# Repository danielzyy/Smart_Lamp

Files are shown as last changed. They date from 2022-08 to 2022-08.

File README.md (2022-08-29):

# Smart_Lamp
Smart lamp built with Adafruit Circuit Playground Express board.

Three modes (manual light, sound light, and alarm) are cycled through by pressing the mode button on the back left of the lamp.
The slide switch on the board toggles between two light modes(solid ring color cycle and rainbow ring cycle).
The left and right buttons on the board are also used in the sound light and alarm modes.
## Modes
### Manual Light (Mode 0)
<b>Two lighting modes: </b> <br>
| Solid Ring Color Cycle (Slide switch to the left) | Rainbow Ring Cycle (Slide switch to the right) |
| --- | --- |
| |  |

<b>Brightness Control Using Rotary Encoder</b>
* Turning left increases brightness of lamp
* Turning right decreases brightness of lamp
* Pressing on the rotary encoder pauses/resumes the color cycle in solid ring color cycle mode.

### Sound Light (Mode 1)
Lights are triggered by noise that exceeds the sound limit. The sound limit is displayed at the top of the display and can be increased or decreased using the left and right buttons on the board.

Brightness of the lights are still controlled by the rotary encoder(same as Mode 0).

### Alarm (Mode 2)
Alarm time is set with the left and right buttons on the board (left button increases hours and right button increases minutes). Pressing on the encoder turns the alarm on. The status of the alarm is displayed at the top of the screen (ON/OFF). <b> Must switch back to Mode 0 or 1 after turning on alarm for it to ring. </b><br>

To turn off ringing alarm, hold down the encoder button until ringing stops.

## Circuit
[Schematic Diagram](https://github.com/danielzyy/Smart_Lamp/tree/main/Circuit%20Schematic)

 

## 3D Model Assembly
[Assembly and Part files (With STL)](https://github.com/danielzyy/Smart_Lamp/tree/main/Solidworks%20Models)

* Top compartment slides over Adafruit board to diffuse light
* Middle compartment holds all electronic components except for the RTC
* Bottom compartment holds hte RTC and any batteries needed, with cables routed through to the middle compartment
* All parts were 3D printed with 25% density



## Bill of Materials
Component                           | Qty | Link
------------------------------------| :-: | ----
Adafruit Circuit Playground Express | 1 | https://www.adafruit.com/product/3333
SSD1306 128x32 OLED Display         | 1 | https://www.amazon.ca/dp/B085NHM5TC
DS1307 AT24C32 RTC                  | 1 | https://www.amazon.ca/dp/B07GGM7GL4
Rechargable 3.6V Coin Cell for RTC  | 1 | https://www.amazon.ca/dp/B09TTSNM31
Rotary Encoder with Push Button     | 1 | https://www.amazon.ca/dp/B08728K3YB
Push Button                         | 1 | https://www.amazon.ca/dp/B07DFDS7W8
Resistor 220Ohm                     | 2 | https://www.digikey.com/en/products/detail/stackpole-electronics-inc/CF18JT220R/1741639
Resistor 10kOhm                     | 2 | https://www.digikey.com/en/products/detail/stackpole-electronics-inc/CF14JT10K0/1741265
Capacitor 1uF                       | 2 | https://www.digikey.com/en/products/detail/murata-electronics/RDER71H105K2M1H03A/4771301

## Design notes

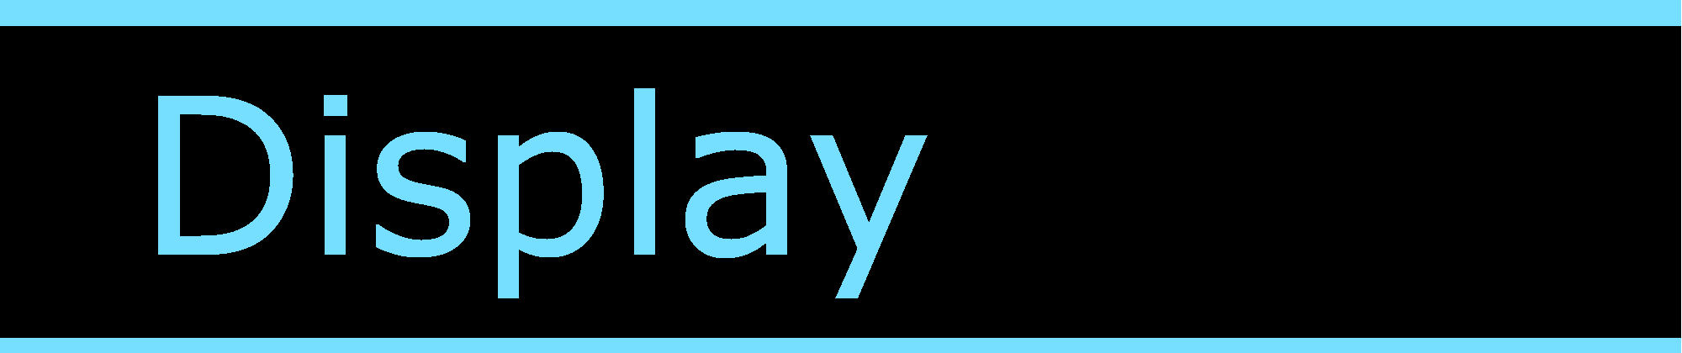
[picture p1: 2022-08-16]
Solidworks Models/Display.png

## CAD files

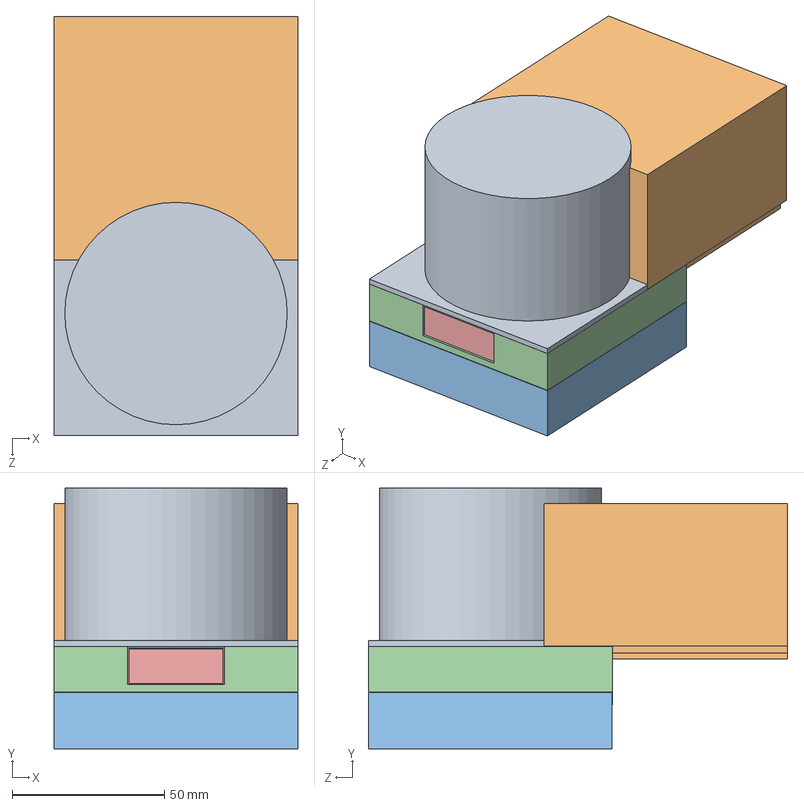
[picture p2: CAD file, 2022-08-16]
Solidworks Models/lamp_asm.SLDASM
80.0 x 85.7 x 137.6 mm
battery_base
board_base
Board.step
10uF.step x 2
10K.step x 17
RED.step x 2
KMR2.step
MicroB USB.step
3-6VDC.step
MBR120.step x 2
EG1390.step
EVQQ.step x 2
WS2812B3535.step x 10
LIS3DH.step
ALS-PT19-315C.step
THERM.step
AP2112K-3.3.step
7.5mm SPK.step
ATSAMD21G18MU.step
SPI FLASH.step
6V+ 500mA.step
MIC_PDM.step
VSOP383.step
IR TX.step x 2
PAM8301.step
mmbt2222.step
OLED_Display_32x128
lamp_top_square
lamp_top_circle_cover

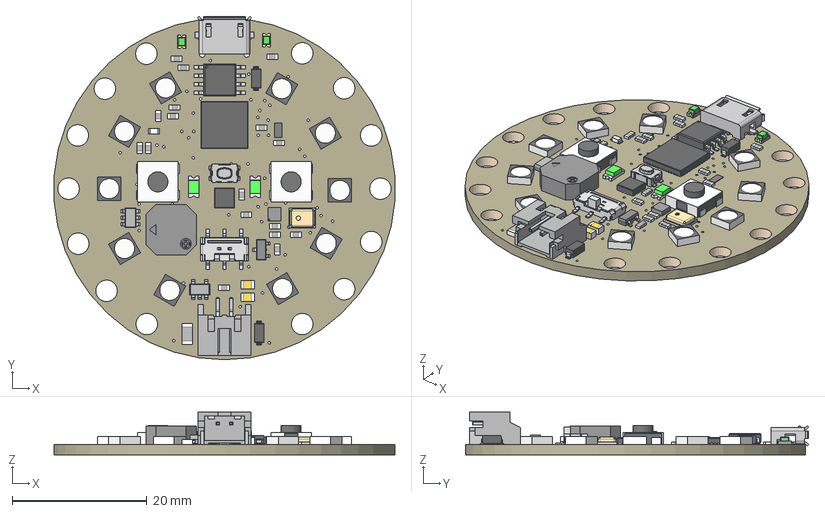
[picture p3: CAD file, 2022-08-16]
Solidworks Models/3333 Circuit Playground Express.step
50.7 x 51.1 x 6.37 mm
Board
10uF x 2
10K x 17
RED x 2
KMR2
MicroB USB
3-6VDC
MBR120 x 2
EG1390
EVQQ x 2
WS2812B3535 x 10
LIS3DH
ALS-PT19-315C
THERM
AP2112K-3.3
7.5mm SPK
ATSAMD21G18MU
SPI FLASH
6V+ 500mA
MIC_PDM
VSOP383
IR TX x 2
PAM8301
mmbt2222

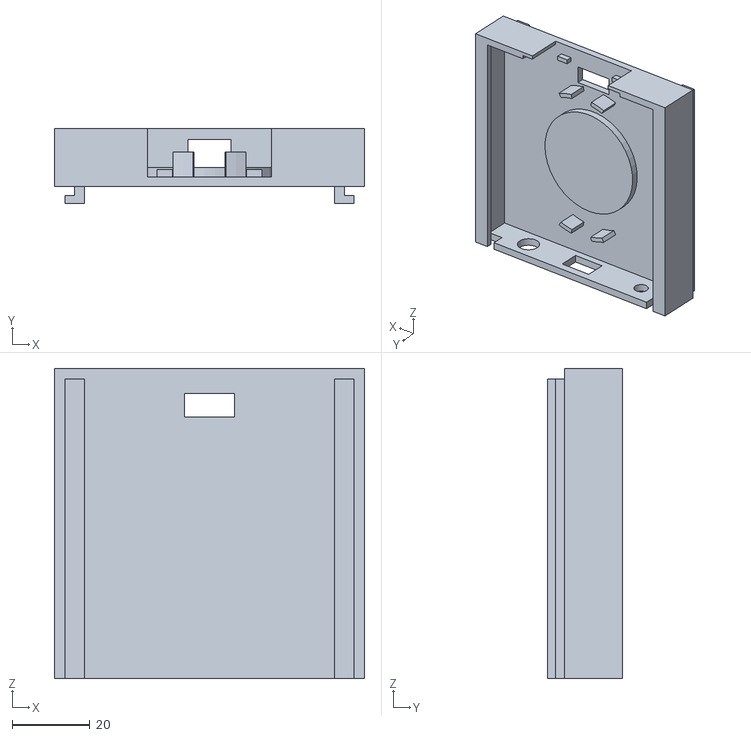
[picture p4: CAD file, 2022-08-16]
Solidworks Models/board_basev2.STL
80.0 x 19.3 x 80.0

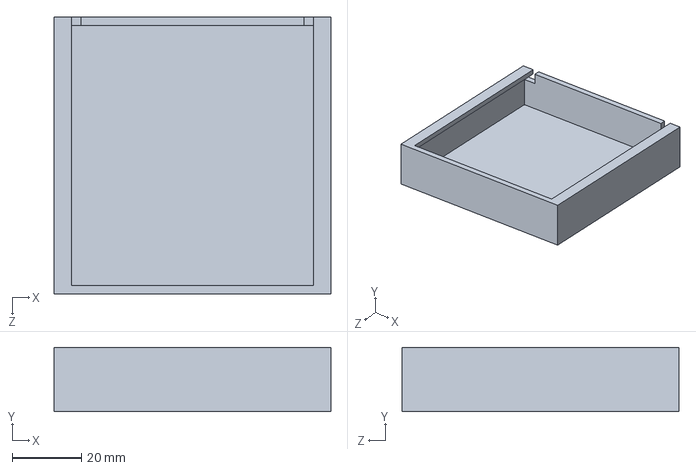
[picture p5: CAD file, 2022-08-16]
Solidworks Models/battery_base.SLDPRT
80.0 x 18.5 x 80.0 mm

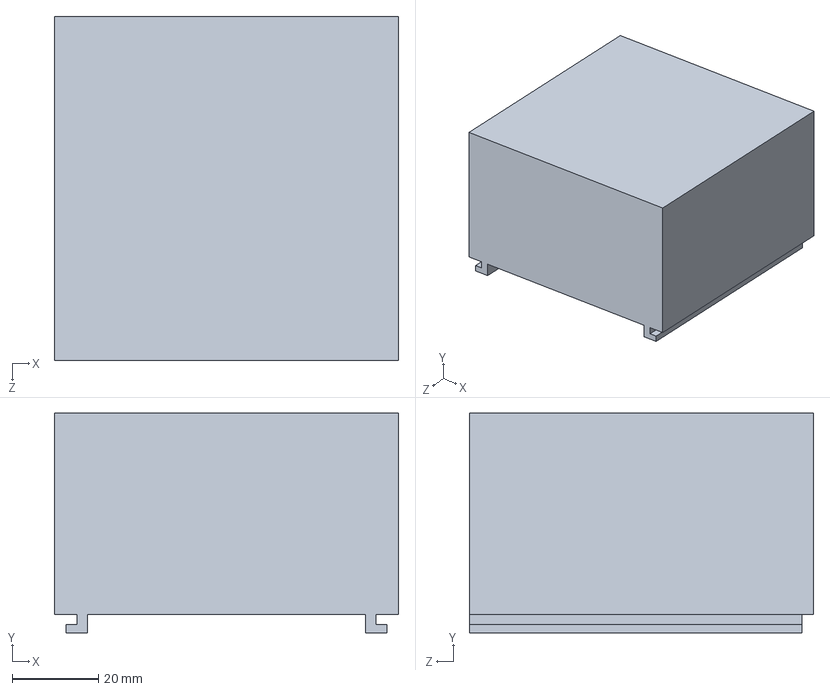
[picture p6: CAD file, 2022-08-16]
Solidworks Models/lamp_top_square.SLDPRT
80.0 x 51.1 x 80.0 mm

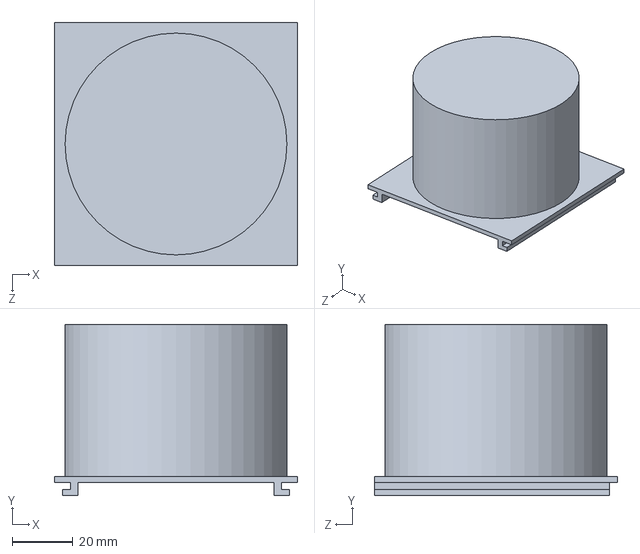
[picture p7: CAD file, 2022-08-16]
Solidworks Models/lamp_top_circle_cover.SLDPRT
80.0 x 56.3 x 80.0 mm

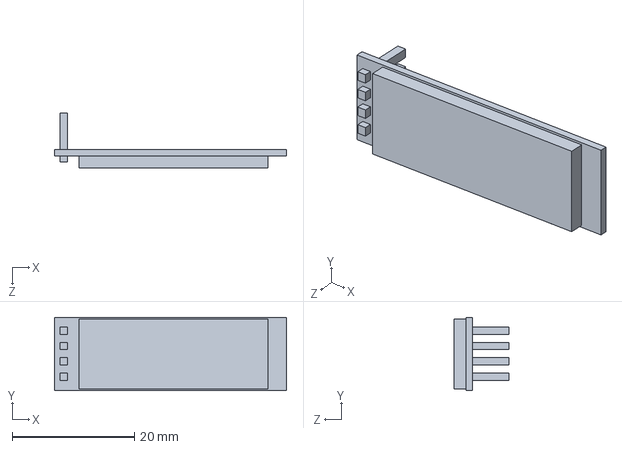
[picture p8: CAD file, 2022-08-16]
Solidworks Models/OLED_Display_32x128.SLDPRT
38.0 x 12.0 x 9.00 mm

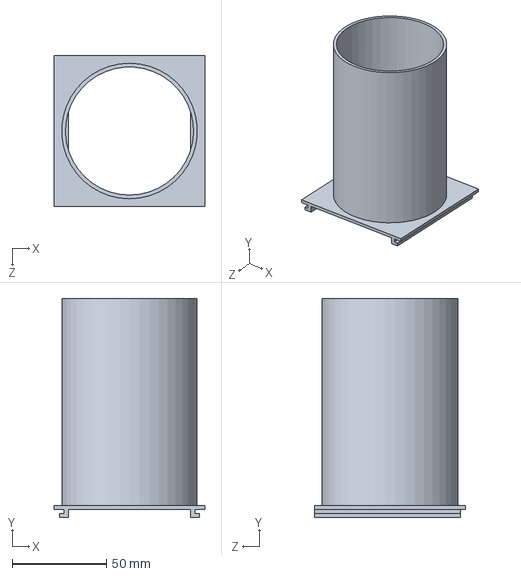
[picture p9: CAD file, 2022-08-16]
Solidworks Models/lamp_top.SLDPRT
80.0 x 116.3 x 80.0 mm

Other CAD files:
Solidworks Models/board_base.SLDPRT
Solidworks Models/3333 CircuitPlaygroundExpress.SLDPRT
Solidworks Models/3333 CircuitPlaygroundExpress.stl
Solidworks Models/battery_base.STL
Solidworks Models/lamp_top_circle_cover.STL
Solidworks Models/lamp_top_square.STL

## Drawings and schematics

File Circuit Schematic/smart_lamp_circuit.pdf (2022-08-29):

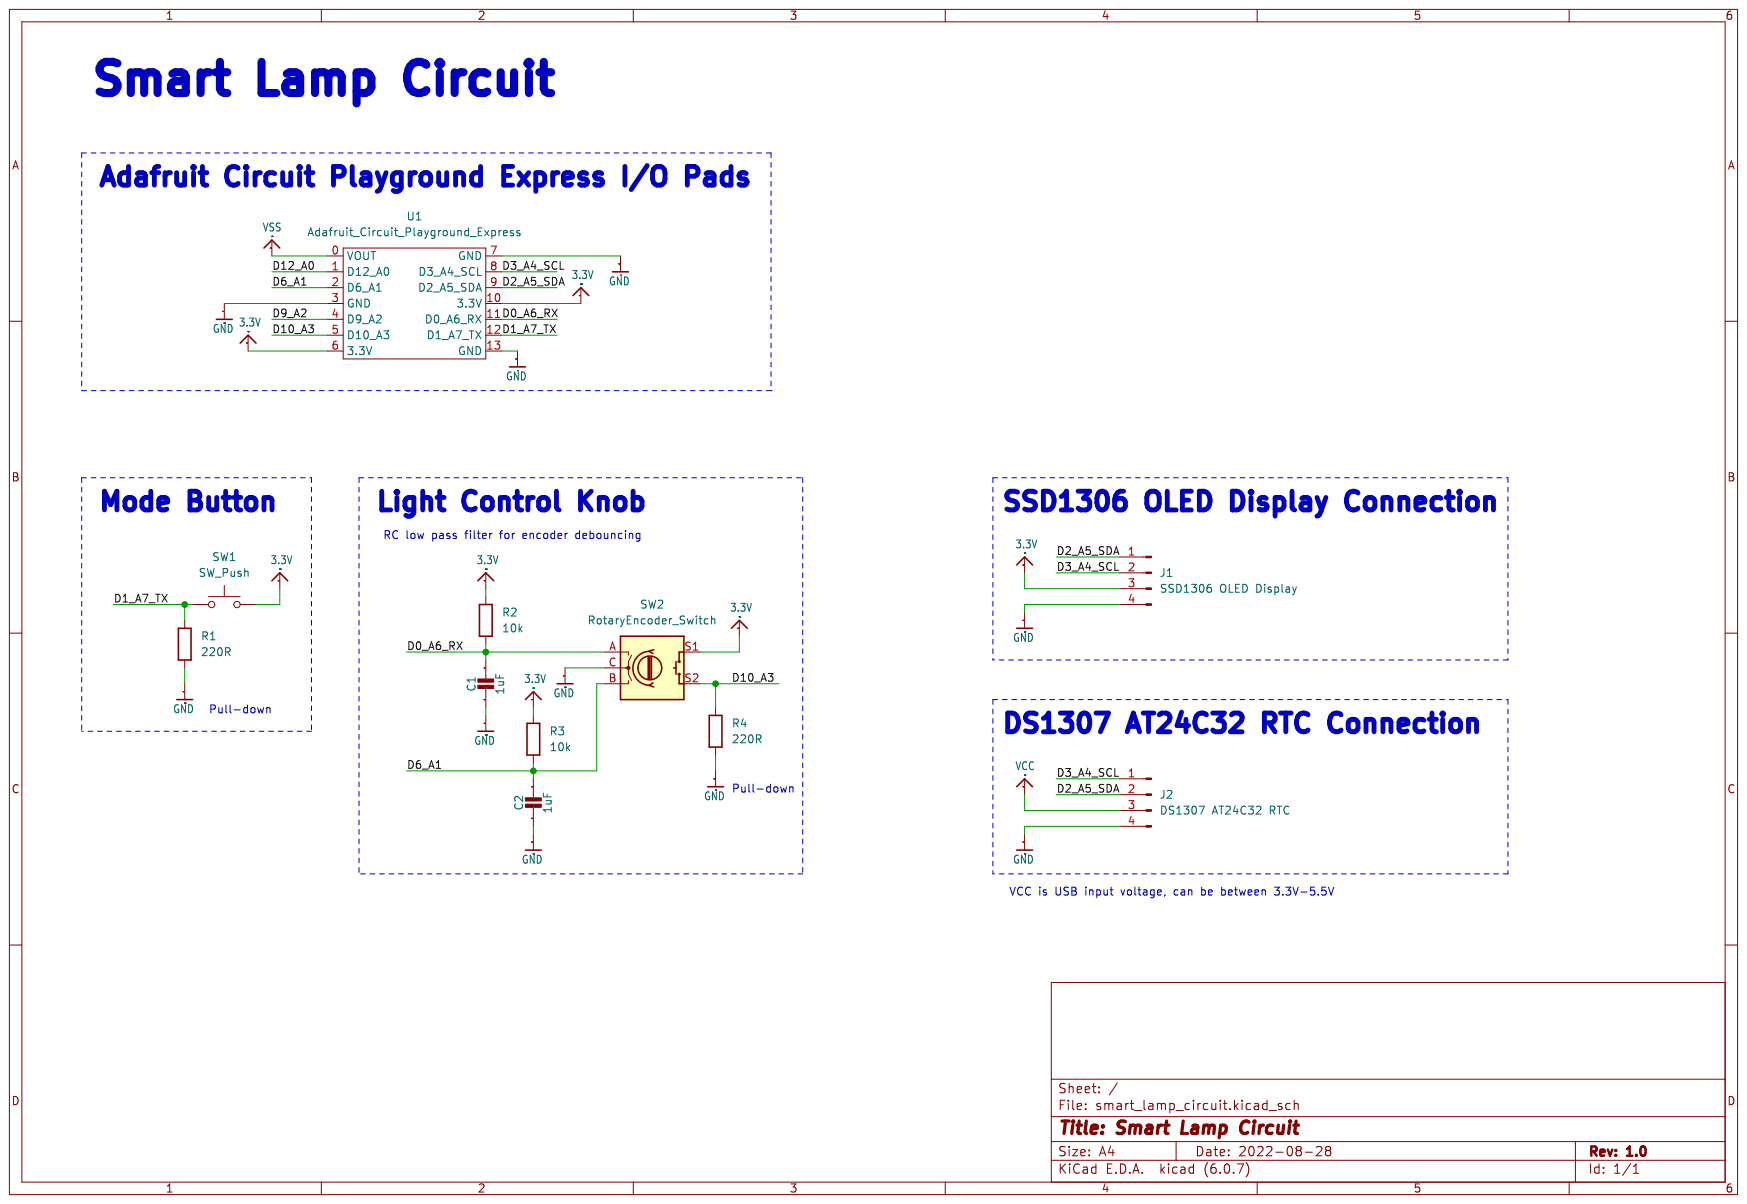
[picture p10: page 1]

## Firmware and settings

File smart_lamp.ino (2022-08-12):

#include <TimeLib.h>
#include <Adafruit_CircuitPlayground.h>
#include <Wire.h>
#include <Adafruit_GFX.h>
#include <Adafruit_SSD1306.h>
#include "RTClib.h"

#define DEBUG true

#define SCREEN_WIDTH 128 // OLED display width, in pixels
#define SCREEN_HEIGHT 32 // OLED display height, in pixels
#define OLED_RESET     -1 // Reset pin # (or -1 if sharing Arduino reset pin)
#define SCREEN_ADDRESS 0x3C ///< See datasheet for Address; 0x3D for 128x64, 0x3C for 128x32
#define TEMP_OFFSET -3.9
#define RING_SPEED_MS 15
#define RAINBOW_SPEED 10

Adafruit_SSD1306 display(SCREEN_WIDTH, SCREEN_HEIGHT, &Wire, OLED_RESET, SCREEN_ADDRESS);
RTC_DS1307 rtc;

// Pin numbers
int encoderPinA = 0;
int encoderPinB = 6;
int lightButtonPin = 10; // encoder button
int modeButtonPin = 1;

enum Modes {
  MANUAL = 0, // Control lamp manually using encoder
  SOUND, // Control lamp using sound level
  ALARM, // Set alarm
  END
};
enum Modes mode = MANUAL;

// Button and light states
int currLightButtonState = 0;
int prevLightButtonState = 0;
int currModeButtonState = 0;
int prevModeButtonState = 0;
bool leftButtonState = false;
bool rightButtonState = false;
bool isRainbow = true;
int colorWheelState = 0;

// LED rainbow speed
int ledTimer = millis();
float peakSound = 0;
int brightness = 90;
// Sound light
bool isLightOn = false;
int soundLimit = 80;
int soundTimer = millis();

// Temperature
float avgTemp = 0;
float sumTemp = 0;
int numTemps = 0;
int tempTimer = millis();

// Alarm timer
int alarm_h = 0;
int alarm_m = 0;
bool isAlarmOn = false;

bool isLightButtonPressed() {
  if(currLightButtonState == 1 && prevLightButtonState == 0)
    return true;
  else
    return false;
}

bool isModeButtonPressed() {
  if(currModeButtonState == 1 && prevModeButtonState == 0)
    return true;
  else
    return false;
}

bool isLeftButtonPressed() {
  if(leftButtonState == false && CircuitPlayground.leftButton() == true)
    return true;
  else
    return false;
}

bool isRightButtonPressed() {
  if(rightButtonState == false && CircuitPlayground.rightButton() == true)
    return true;
  else
    return false;
}

void ringCycle(int ledSpeed) {
  if (millis()-ledTimer>ledSpeed && isRainbow == true) {
    colorWheelState++;
    ledTimer = millis();
  }
  if (colorWheelState > 255)
    colorWheelState = 0;
  for(int i=0; i<10; i++) {
    CircuitPlayground.setPixelColor(i,CircuitPlayground.colorWheel(colorWheelState));
  }
  if(isLightButtonPressed()) {
    isRainbow = !isRainbow;
    #if DEBUG
      Serial.println("TOGGLED LIGHT");
    #endif
  }
}

void rainbowCycle(int rainbowSpeed) {
  int offset = millis() / rainbowSpeed;
  // Loop through each pixel and set it to an incremental color wheel value.
  for(int i=0; i<10; ++i) {
    CircuitPlayground.strip.setPixelColor(i, CircuitPlayground.colorWheel(((i * 256 / 10) + offset) & 255));
  }
  CircuitPlayground.strip.show();
}

void manualLight() {
  if (CircuitPlayground.slideSwitch()) {
    ringCycle(RING_SPEED_MS);
  }
  else {
    rainbowCycle(RAINBOW_SPEED);
  }
}

void soundLight() {
  float soundLevel = CircuitPlayground.mic.soundPressureLevel(10);
  if (millis()-soundTimer < 100) {
    if(soundLevel > peakSound)
      peakSound = soundLevel;
  } else {
    if (peakSound > soundLimit) {
      isLightOn = !isLightOn;
      #if DEBUG
        Serial.print("Sound toggled at: ");
        Serial.println(peakSound);
      #endif
    }
    soundTimer = millis();
    peakSound = 0;
  }
  if (isLightOn) {
    if (CircuitPlayground.slideSwitch()) {
      ringCycle(RING_SPEED_MS);
    }
    else {
      rainbowCycle(RAINBOW_SPEED);
    }
  }
  else {
    CircuitPlayground.clearPixels();
  }
}

void updateTemp() {
  float temp = CircuitPlayground.temperature()+TEMP_OFFSET;
  if (millis()-tempTimer < 1000) {
    sumTemp += temp;
    numTemps++;
  } else {
    if(numTemps == 0) // when alarm is ringing, numTemps does not increment
      avgTemp = temp;
    else
      avgTemp = sumTemp/numTemps;
    sumTemp = 0;
    numTemps = 0;
    tempTimer = millis();
  }
}

void display_text() {
  DateTime now = rtc.now();
  // mode text
  display.clearDisplay();
  display.setCursor(0,0);
  display.setTextSize(1);
  display.print("Mode:");
  display.print(mode);
  // sound limit
  if(mode == SOUND) {
    display.print("  L:");
    display.print(soundLimit);
    if(soundLimit >= 100) // limit cannot go above 1000
      display.print(" ");
    else if (soundLimit < 100) // limit cannot go below 10
      display.print("  ");
  } else if(mode==ALARM) {
    display.print("   ");
    if(isAlarmOn)
      display.print("ON   ");
    else
      display.print("OFF  ");
  } else {
    display.print("        ");
  }
  // temperature text
  display.print(avgTemp);
  display.println(" C");

  // time text
  display.setCursor(0,11);
  display.setTextSize(3);
  display.setTextColor(SSD1306_WHITE);
  int display_h = now.hour();
  int display_m = now.minute();
  // display alarm time when in alarm mode
  if(mode == ALARM) {
    display_h = alarm_h;
    display_m = alarm_m;
  }
  if (display_h % 12 < 10) {
    if(display_h == 12 || display_h == 0)
      display.print("12");
    else {
      display.print(" ");
      display.print(display_h % 12);
    }
  }
  else {
    display.print(display_h % 12);
  } 
  display.print(":");
  if(display_m<10) {
    display.print("0");
    display.println(display_m);
  } else {
    display.println(display_m);
  }
  display.setTextSize(2);
  display.setCursor(display.width()-28,display.height()-14);
  if(display_h < 12)
    display.println("AM");
  else
    display.println("PM");
  display.drawCircle(display.width()-12, 2, 2, SSD1306_WHITE);
  display.display();
}

void changeAlarm() {
  CircuitPlayground.clearPixels();
  if (isLeftButtonPressed()) {
    if(alarm_h == 23)
      alarm_h = 0;
    else
      alarm_h++;
  }
  if (isRightButtonPressed()) {
    if(alarm_m == 59)
      alarm_m = 0;
    else
      alarm_m++;
  }
  if(isLightButtonPressed()) {
    isAlarmOn = !isAlarmOn;
  }
}

void changeSoundLimit() {
  if (isLeftButtonPressed()) {
    if(soundLimit > 10)
      soundLimit-=5;
    isLightOn = true;
  }
  if (isRightButtonPressed()) {
    if(soundLimit < 1000)
      soundLimit+=5;
    isLightOn = true;
  }
}

void setMode() {
  if(isModeButtonPressed()) {
    mode = static_cast<Modes>(mode+1);
    if(mode == END) {
      mode = MANUAL;
    }
    #if DEBUG
      Serial.println("TOGGLED MODE");
    #endif
  }
}

void setBrightness() {
  if(digitalRead(encoderPinB) == 1) {
    if(brightness < 255) {
      brightness+=5;
    }
    #if DEBUG
      Serial.println("CW");
    #endif
  } else {
    if(brightness > 0) {
      brightness-=5;
    }
    #if DEBUG
      Serial.println("CCW");
    #endif
  }
  CircuitPlayground.setBrightness(brightness);
}

void checkAlarm() {
  if(isAlarmOn && rtc.now().hour() == alarm_h && rtc.now().minute() == alarm_m) {
    CircuitPlayground.playTone(440,500);
    if(currLightButtonState == true) {
      isAlarmOn = false;
    }
  }
}

void changeTime() { // depreciated when using RTC
  CircuitPlayground.clearPixels();
  if (isLeftButtonPressed()) {
    adjustTime(3600);
  }
  if (isRightButtonPressed()) {
    adjustTime(60);
  }
}

void setup() {
  #if DEBUG
    Serial.begin(9600);
    Serial.println("Debug Mode");
  #endif
  CircuitPlayground.begin();
  if (! rtc.begin()) {
    #if DEBUG
      Serial.println("Couldn't find RTC");
      Serial.flush();
    #endif
//    while (1) delay(10);
  }
//  rtc.adjust(DateTime(F(__DATE__), F(__TIME__))); // uncomment to set time
  // SSD1306_SWITCHCAPVCC = generate display voltage from 3.3V internally
  if(!display.begin(SSD1306_SWITCHCAPVCC, SCREEN_ADDRESS)) {
    #if DEBUG
      Serial.println(F("SSD1306 allocation failed"));
    #endif
    for(;;); // Don't proceed, loop forever
  }
  display.display();
  display.clearDisplay();
  setTime(0,0,0,15,3,2022);
  pinMode(modeButtonPin, INPUT);
  pinMode(lightButtonPin, INPUT_PULLDOWN);
  pinMode(encoderPinA, INPUT);
  pinMode(encoderPinB, INPUT);
  attachInterrupt(digitalPinToInterrupt(encoderPinA), setBrightness, RISING);
  CircuitPlayground.setBrightness(brightness);
  currModeButtonState = digitalRead(modeButtonPin);
  currLightButtonState = digitalRead(lightButtonPin);
 }

void loop() {
  currModeButtonState = digitalRead(modeButtonPin);
  currLightButtonState = digitalRead(lightButtonPin);
  setMode();
  updateTemp();
  display_text();
  if(mode == MANUAL) {
    manualLight();
  } else if (mode == SOUND) {
    soundLight();
    changeSoundLimit();
  } else if (mode == ALARM) {
    changeAlarm();
  }
  if(mode != ALARM) {
    checkAlarm();
  }
  leftButtonState = CircuitPlayground.leftButton();
  rightButtonState = CircuitPlayground.rightButton();
  prevModeButtonState = currModeButtonState;
  prevLightButtonState = currLightButtonState;
}

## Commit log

2022-08-12 Uploaded Arduino code file
2022-08-16 added 3d model files
    [3333 Circuit Playground Express.step, 3333 CircuitPlaygroundExpress.SLDPRT, 3333 CircuitPlaygroundExpress.stl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]
2022-08-25 added circuit images
2022-08-29 Updated with BOM
2022-08-29 added smart lamp circuit
    [smart_lamp_circuit.kicad_sch]
2022-08-29 Updated readme with links to schematic and models
